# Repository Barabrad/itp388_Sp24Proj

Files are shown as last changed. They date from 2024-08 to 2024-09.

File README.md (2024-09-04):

# itp388_Sp24Proj
This is our group's project for ITP-388 in Spring 2024.

## Project Info
This project was compiled with the PlatformIO IDE extension in VSCode, so folders like `.vscode` or `test` were generated by the extension upon the creation of the project.

We used GitHub as we developed the software, and submitted it as part of our final deliverable in May 2024. However, I tidied up the repo (which required rebases) in August and September of 2024.

I also added the files we made that related to the hardware (3D-printing, PCBs, etc.) in the `Hardware` folder.

To see more about our project, visit [https://barabrad.github.io/engineering_portfolio/itp388proj](https://barabrad.github.io/engineering_portfolio/itp388proj)

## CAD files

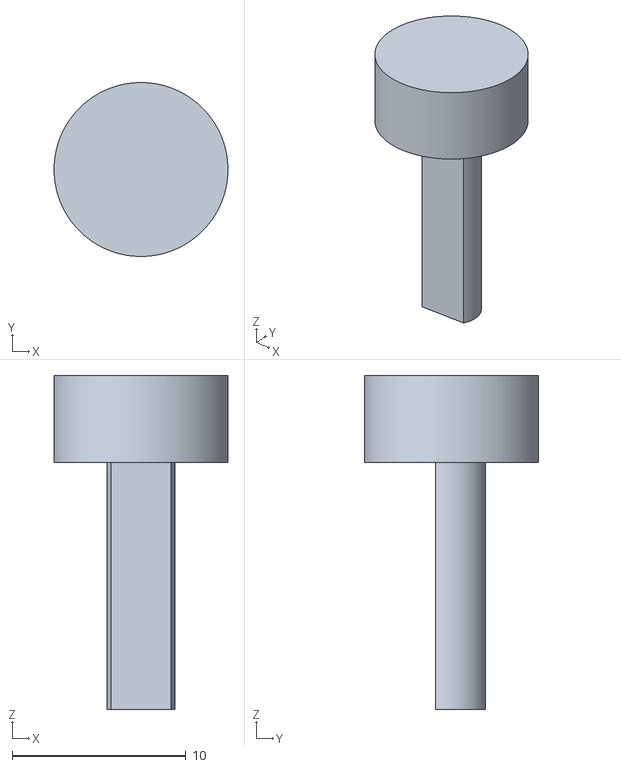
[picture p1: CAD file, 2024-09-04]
Hardware/STLs/Tilt Sensor Knob Round v2.stl
10.0 x 10.00 x 19.2

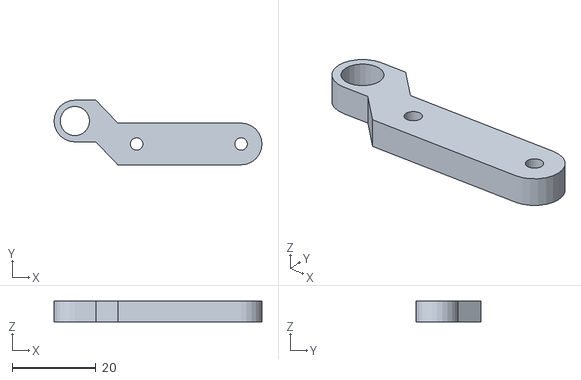
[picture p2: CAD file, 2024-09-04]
Hardware/STLs/Hinge.stl
49.8 x 15.5 x 5.00

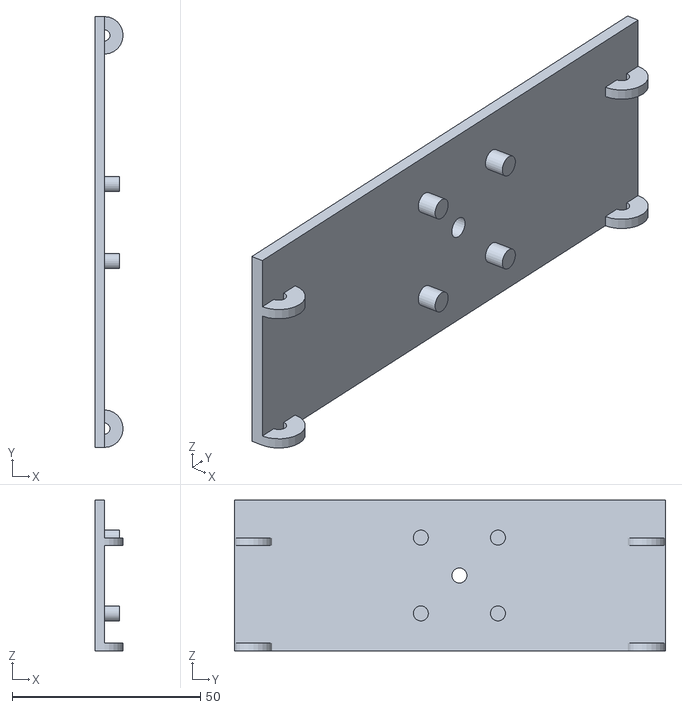
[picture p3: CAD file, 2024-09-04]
Hardware/STLs/InWall.stl
7.50 x 114.5 x 40.0

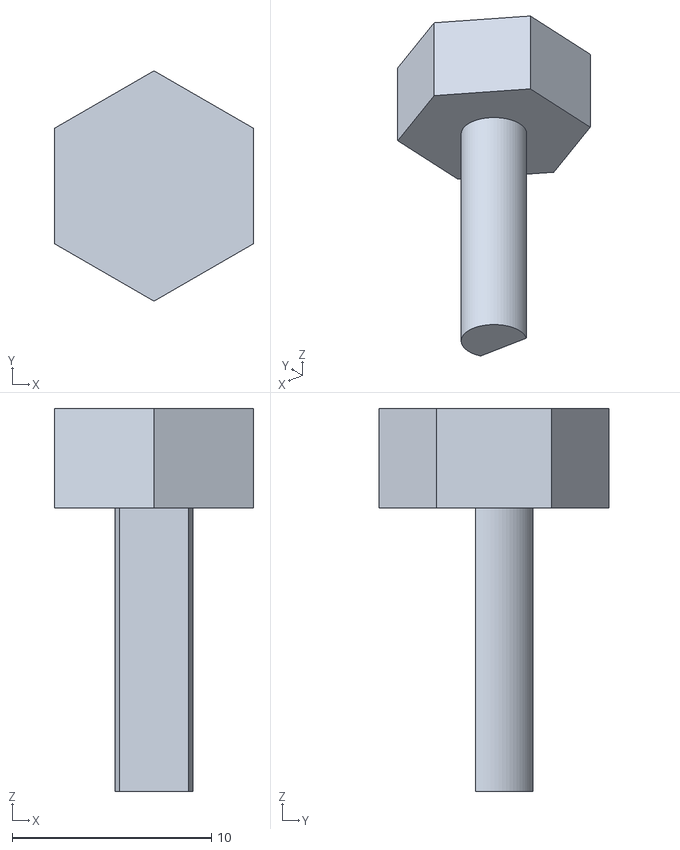
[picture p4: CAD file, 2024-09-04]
Hardware/STLs/Tilt Sensor Knob Hexagon v2.stl
10.0 x 11.5 x 19.2

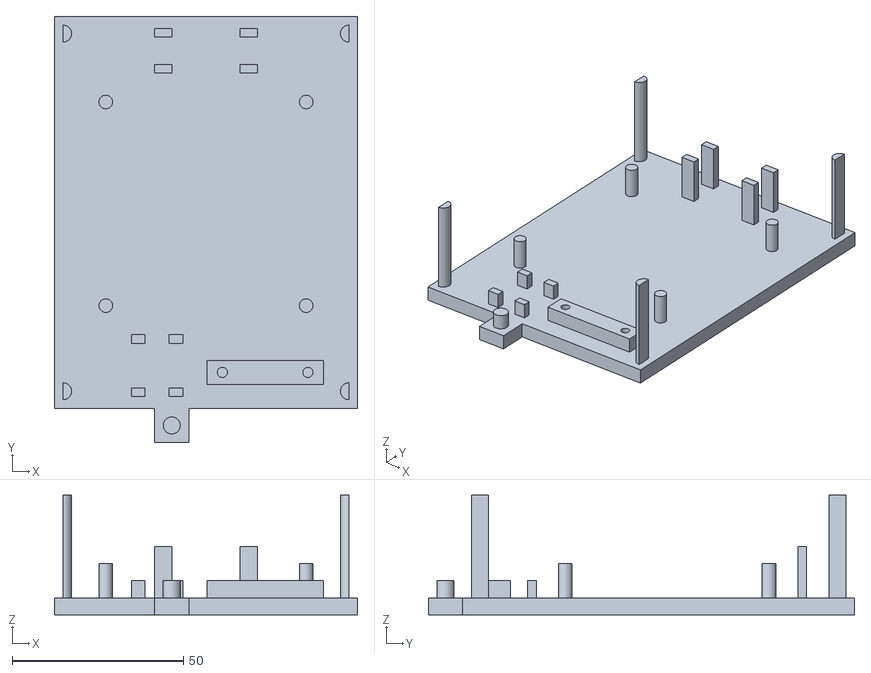
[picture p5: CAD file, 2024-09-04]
Hardware/STLs/EncBottom.stl
88.6 x 124.5 x 35.0

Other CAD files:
Hardware/STLs/InWall(Mirror).stl

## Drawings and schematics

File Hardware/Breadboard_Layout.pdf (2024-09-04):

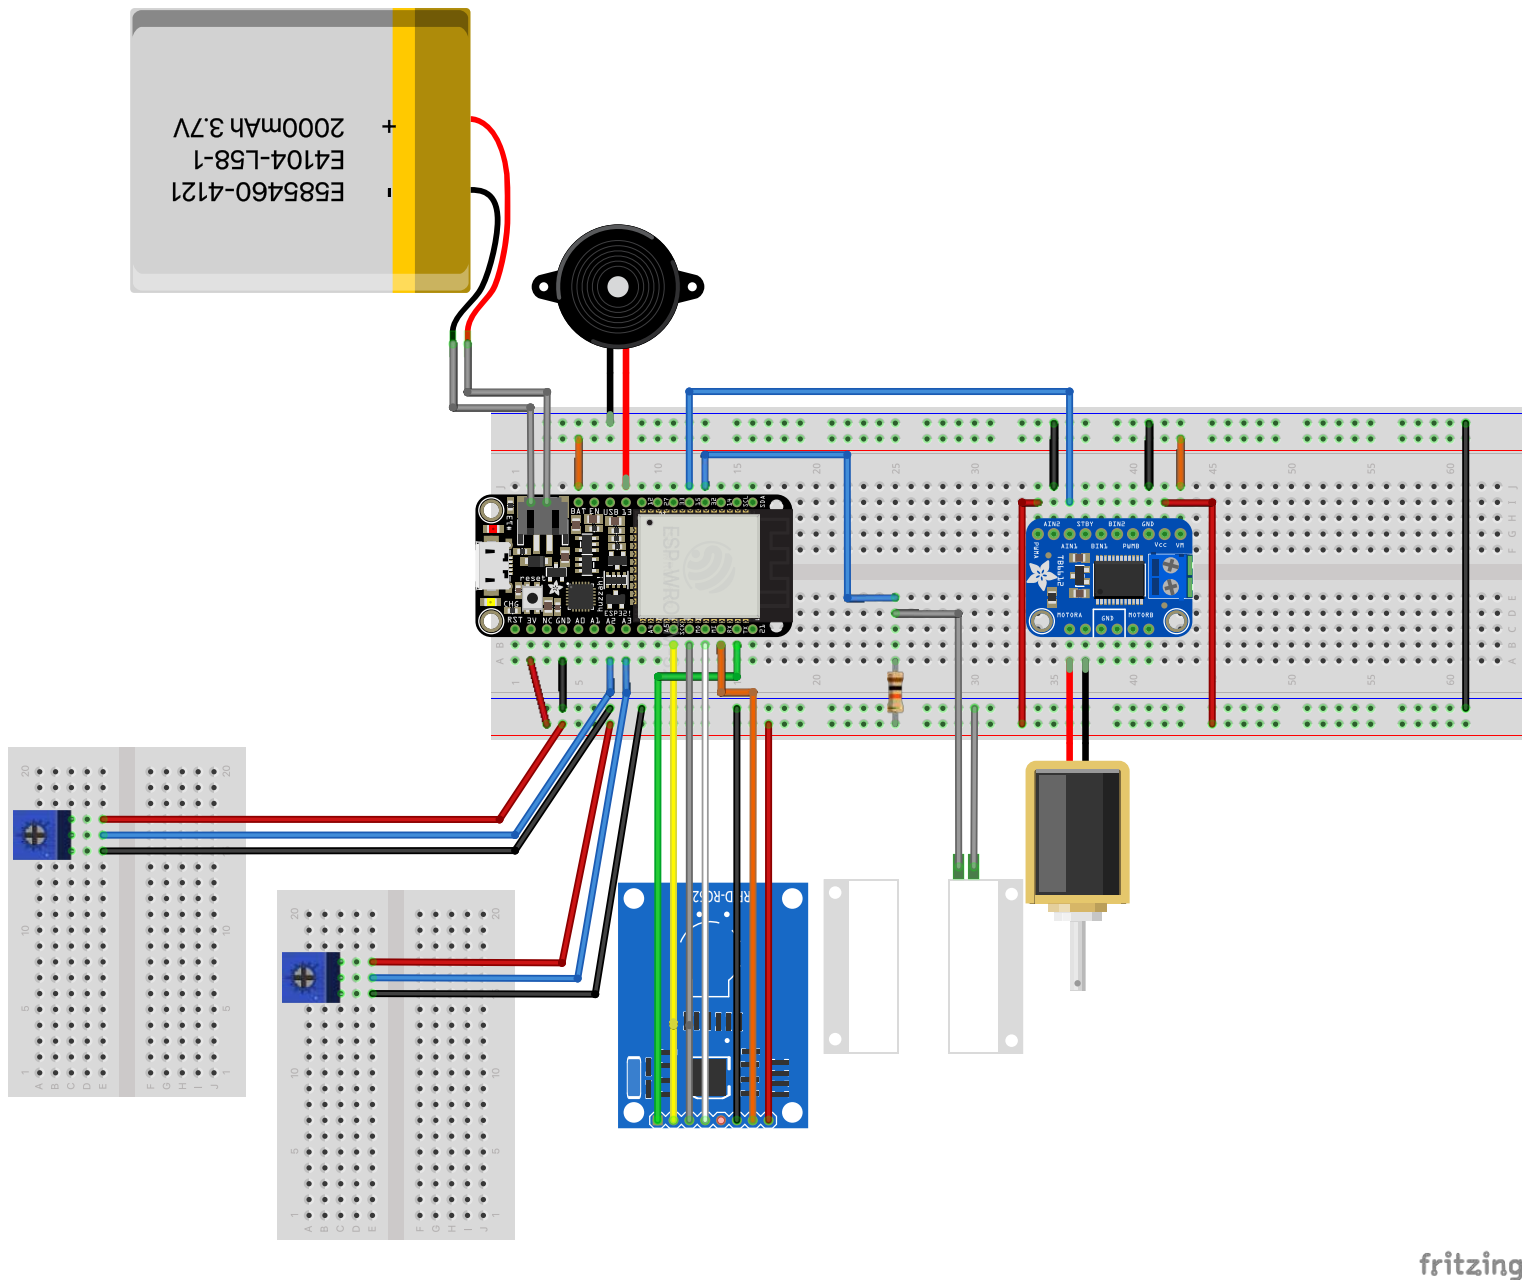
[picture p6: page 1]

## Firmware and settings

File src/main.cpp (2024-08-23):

// WiFi and Blynk Credentials
#include "secrets_def.h" // Default
//#include "secrets.h" // Specific (user must make this file)

#include <Arduino.h>
#include <WiFi.h>
#include <WiFiClient.h>
#include <BlynkSimpleEsp32.h>
#include "pitches.h"
#include <Wire.h> 
#include <MFRC522.h>
#include <SPI.h>

typedef unsigned long u_long;

// Your WiFi credentials.
// Set password to "" for open networks.
// https://examples.blynk.cc/?board=ESP32&shield=ESP32%20WiFi&example=GettingStarted%2FBlynkBlink
char ssid[] = SECRET_SSID;
char pass[] = SECRET_PASS;


// ***************************** //
// ***** Constant Globals ****** //
// ***************************** //
// Pins
const uint8_t BUZZER_PIN = 13; // Adjust values based on pin mapping
const uint8_t MAGSWITCH_PIN = 32;
const uint8_t TILT_IN_PIN = 34; // Tilt sensor on the inside
const uint8_t TILT_OUT_PIN = 39; // Tilt sensor on the outside (can override locking)
const uint8_t SOLENOID_PIN = 15;
const uint8_t SS_PIN = 17; // SDA for RFID Reader
const uint8_t RST_PIN = 16; // Reset for RFID Reader
const uint8_t BAT_PIN = A13; // https://learn.adafruit.com/adafruit-huzzah32-esp32-feather/power-management#measuring-battery-3122383
const uint8_t BUT_VAL_PIN = 21; // To simulate valid RFID swipe
const uint8_t BUT_INVAL_PIN = 23; // To simulate invalid RFID swipe
// Array for notes (zeros are rests)
const uint8_t BPM = 135; // Beats per minute
const float BPS = BPM/60.0; // Beats per second
const uint8_t NATURAL_GAP = 50; // Natural delay of switching note, ms
// Melody (valid card)
const uint8_t MELODY_LEN = 29; // # of notes (including rests)
const uint16_t MELODY[MELODY_LEN] = {NOTE_GS3, NOTE_AS3, NOTE_CS4, NOTE_AS3, NOTE_F4, NOTE_F4, NOTE_DS4, 0, NOTE_GS3, NOTE_AS3, NOTE_CS4, NOTE_AS3, NOTE_DS4, NOTE_DS4, NOTE_CS4, NOTE_C4, NOTE_AS3, NOTE_GS3, NOTE_AS3, NOTE_CS4, NOTE_AS3, NOTE_CS4, NOTE_DS4, NOTE_C4, NOTE_AS3, NOTE_GS3, NOTE_GS3, NOTE_DS4, NOTE_CS4};
const float MELODY_BEATS[MELODY_LEN] = {0.25, 0.25, 0.25, 0.25, 0.75, 0.75, 1, 0.5, 0.25, 0.25, 0.25, 0.25, 0.75, 0.75, 0.75, 0.25, 0.5, 0.25, 0.25, 0.25, 0.25, 1, 0.5, 0.75, 0.25, 1, 0.5, 1, 1};
// Tritone (invalid card)
const uint8_t TRITONE_LEN = 2; // # of notes (including rests)
const uint16_t TRITONE[TRITONE_LEN] = {NOTE_F5, NOTE_B4};
const float TRITONE_BEATS[TRITONE_LEN] = {0.5, 0.5};
// Warning
const uint8_t WARNING_LEN = 5; // # of notes (including rests)
const uint16_t WARNING[WARNING_LEN] = {NOTE_G5, NOTE_F5, NOTE_D5, NOTE_C5, NOTE_A4};
const float WARNING_BEATS[WARNING_LEN] = {0.5, 0.5, 0.5, 0.5, 1};
// Timing
const u_long TIME_OPEN = 15000; // 15 seconds
const u_long SCAN_DELAY = 5000; // 5 seconds
const u_long WARNING_DELAY = 10000; // 10 seconds
const u_long TIME_ACTUATE = 2000; // 2 seconds (to push the lock to close)
const u_long BAT_UPDATE = 60000; // 60 seconds
const u_long TIME_TBST = 5000; // 5 seconds for each troubleshoot packet

// ***************************** //
// **** Non-Const. Globals ***** //
// ***************************** //
// Timing
u_long prevMillisDoor = 0;
u_long prevMillisScan = 0;
u_long prevMillisWarning = 0;
u_long prevMillisSound = 0;
u_long prevMillisAct = 0;
u_long prevMillisBat = 0;
u_long prevMillisTbst = 0; // For troubleshooting tilt
// Controls
const bool DO_TBST = false; // Enable/disable troubleshooting packets
const bool USE_BUT_FOR_CARD = false; // Enable buttons for testing if RDID is unavailable
bool doorOpen = false;
bool prevActuated = false;
bool actuated = false;
//bool justCheckedRFID = false;
// Other
uint8_t tilt_position = 0;
float batVoltage = -1;
uint8_t overrideVal = 0;

// Initialize RFID reader
MFRC522 mfrc522(SS_PIN, RST_PIN); // Create MFRC522 instance.
String rfid = "";
const String VALID_CARDS[] = {"61 C5 7A 10"}; // The card that came with the reader
// RFID tag (for invalid demo): 03 E2 0C 50

// Unorganized variables for non-blocking speaker code
uint8_t noteIndex = 0;
bool grant_access = false;
bool deny_access = false;
bool warning = false;
u_long pauseBetweenNotes = 0;

// ***************************** //
// ***** Helper Functions ****** //
// ***************************** //
void playSongWithDelay(const uint16_t* melody, const float* beats, const uint8_t len) {
  // Just for now, we're going to use delay()
  // To calculate the note time, we will use the beats/sec and the number of beats for each note
  for (int i = 0; i < len; i++) {
    int note_i = melody[i];
    float beats_i = beats[i];
    // Goal: Play the note and have a delay
    int noteTime = (beats_i/BPS)*1000; // ms
    if (note_i != 0) {
      tone(BUZZER_PIN, note_i, noteTime);
    }
    delay(noteTime + NATURAL_GAP);
    // Uncomment the line below to troubleshoot melody
    //Serial.println("  Note #" + String(i) + " (" + String(beats_i) + " beats, f = " + String(note_i) + " Hz, t = " + String(noteTime) + " ms)");
  }
}

// Plays a sound given inputs of the notes array, duration (beats) array, and number of notes
void playSound(const uint16_t* melody, const float* beats, const int num_notes) {
  // For every note, play the note for its duration (pausing would make the code much more complex)
  if (millis() - prevMillisSound >= pauseBetweenNotes) {
    // Resets noteIndex and boolean variables if play_alarm is true or the last note has been played, without changing play_alarm itself so that the alarm can be played continuously until it is deactivated
    if (noteIndex >= num_notes) {
      noteIndex = 0;
      grant_access = false;
      deny_access = false;
      warning = false;
      pauseBetweenNotes = 0; // Resets pauseBetweenNotes for the next sound that is played
      noTone(BUZZER_PIN); // Stops buzzer
    }
    else {
      prevMillisSound = millis();
      int note_i = melody[noteIndex];
      float beats_i = beats[noteIndex];
      int noteTime = (beats_i/BPS)*1000; // ms
      // Plays the note, but with no duration (since duration is blocking)
      if (note_i == 0) {noTone(BUZZER_PIN);}
      else {tone(BUZZER_PIN, note_i);}
      pauseBetweenNotes = noteTime; // Gap in notes would be hard to do without blocking
      // Increments noteIndex after the note is played
      //Serial.println(String(noteIndex) + ": " + String(note_i) + " Hz");
      noteIndex = noteIndex + 1;
    }
  }
}

void selectSound() {
  if (grant_access) {
    playSound(MELODY, MELODY_BEATS, MELODY_LEN);
  } else if (deny_access) {
    playSound(TRITONE, TRITONE_BEATS, TRITONE_LEN);
  } else if (warning) {
    playSound(WARNING, WARNING_BEATS, WARNING_LEN);
  } //else no sound is played
}

// void grantAccess() {
//   // Play pleasant sound, disable actuator
//   playSongWithDelay(MELODY, MELODY_BEATS, MELODY_LEN);
//   Serial.println("Access granted!");
// }

// void denyAccess() {
//   // Play unpleasant sound, don't disable actuator
//   playSongWithDelay(TRITONE, TRITONE_BEATS, TRITONE_LEN);
//   Serial.println("Access denied.");
// }

// void warning() {
//   // Play warning sound, don't disable actuator
//   playSongWithDelay(WARNING, WARNING_BEATS, WARNING_LEN);
//   Serial.println("Warning.");
// }

void disableAct() {
  // Disable the actuator
  digitalWrite(SOLENOID_PIN, LOW);
  actuated = false;
}

void open() {
  // Open the door
  disableAct();
  doorOpen = true;
  prevMillisDoor = millis();
  Serial.println("Opening door...");
}

void close() {
  // Close the door
  digitalWrite(SOLENOID_PIN, HIGH);
  doorOpen = false;
  actuated = true;
  prevMillisAct = millis();
  Serial.println("Closing door...");
}

bool isTilted(const uint8_t TILT_PIN) {
  // Figure out how to read from tilt sensor
  tilt_position = map(analogRead(TILT_PIN), 0, 4095, 0, 342);
  // Serial.println("Tilt angle: " + String(tilt_position));
  // delay(500);
  //Serial.println(tilt_position); // For testing
  if (tilt_position >= 30 && tilt_position <= 120) { // Adjust values during testing
    Serial.println("Doorknob tilted.");
    return true;
  }
  return false; // Placeholder so we can verify code works
}

bool verifyRFID(String tag) {
  // Verify RFID card
  for (int i = 0; i < sizeof(VALID_CARDS)/sizeof(VALID_CARDS[0]); i++) {
    if (tag == VALID_CARDS[i]) {
      return true;
    }
  }
  return false;
}

String readRFID() {
  String scannedCard = "";
  if (mfrc522.PICC_IsNewCardPresent() == true) {
    if (mfrc522.PICC_ReadCardSerial() == true) {
      for (byte i = 0; i < mfrc522.uid.size; i++) {
        if (mfrc522.uid.uidByte[i] < 0x10) {
          scannedCard = scannedCard + " 0";
        } else {
          scannedCard = scannedCard + " ";
        }
        scannedCard = scannedCard + String(mfrc522.uid.uidByte[i], HEX);
      }
      scannedCard.toUpperCase();
      scannedCard.trim();
      Serial.println("Scanned card: " + scannedCard);
    }
  }
  return scannedCard;
}

BLYNK_WRITE(V2) {
  //prevLockVal = overrideVal;
  overrideVal = param.asInt(); // assigning incoming value from pin V2 to a variable
}

// ***************************** //
// ****** Main Functions ******* //
// ***************************** //
void setup() {
  Serial.begin(9600);
	Wire.begin(); 
  // Begin Blynk
  Blynk.begin(BLYNK_AUTH_TOKEN, ssid, pass);

  delay(2000);
  Blynk.virtualWrite(V1, 0); // Set initial actuation value to false
  Serial.println("Blynk initialized.");

  // Initialize RFID reader
  SPI.begin(); // Init SPI bus
  mfrc522.PCD_Init(); // Init MFRC522
  delay(1000); // Optional delay. Some board do need more time after init to be ready, see Readme
  mfrc522.PCD_DumpVersionToSerial(); // Show details of PCD - MFRC522 Card Reader details

  Serial.println("RFID initialized.");

  // Set up pins
  pinMode(BUZZER_PIN, OUTPUT);
  pinMode(MAGSWITCH_PIN, INPUT);
  pinMode(TILT_IN_PIN, INPUT);
  pinMode(TILT_OUT_PIN, INPUT);
  pinMode(SOLENOID_PIN, OUTPUT);
  pinMode(SS_PIN, OUTPUT);
  pinMode(RST_PIN, OUTPUT);
  pinMode(BAT_PIN, INPUT);
  pinMode(BUT_VAL_PIN, INPUT);
  pinMode(BUT_INVAL_PIN, INPUT);

  Serial.println("Setup complete.");
}

void loop() {
  Blynk.run();
  selectSound();
  prevActuated = actuated;
  // Check tilt values
  if ((millis() - prevMillisTbst > TIME_TBST) && DO_TBST) {
    prevMillisTbst = millis();
    int outer = map(analogRead(TILT_OUT_PIN), 0, 4095, 0, 342);
    int inner = map(analogRead(TILT_IN_PIN), 0, 4095, 0, 342);
    int valid = digitalRead(BUT_VAL_PIN);
    int invalid = digitalRead(BUT_INVAL_PIN);
    Serial.println("(O,I) = (" + String(outer) + "," + String(inner) + ")");
    Serial.println("(V,IV) = (" + String(valid) + "," + String(invalid) + ")");
  }
  // Measure battery voltage
  if ((millis() - prevMillisBat > BAT_UPDATE) || (batVoltage == -1)) {
    prevMillisBat = millis();
    // https://forums.adafruit.com/viewtopic.php?t=196384
    float halfVolt = analogRead(BAT_PIN);
    batVoltage = (halfVolt*2)*(3.3/4096); // 3.3 reference voltage; 12-bit ADC -> 4096 values
    Serial.println("Battery: " + String(batVoltage) + " V");
    Blynk.virtualWrite(V0, batVoltage);
  }
  // Checks actuator (can't keep on for long or else it burns out)
  if (actuated && (millis() - prevMillisAct > TIME_ACTUATE)) {
    prevMillisAct = millis();
    disableAct();
    Serial.println("Actuation time ended.");
  }
  // Checks RFID
  if (!USE_BUT_FOR_CARD) {rfid = readRFID();}
  else {
    if (digitalRead(BUT_VAL_PIN) == HIGH) {rfid = "8B A0 F0 13";}
    else if (digitalRead(BUT_INVAL_PIN) == HIGH) {rfid = "Nuh uh";}
    else {rfid = "";}
  }
  if (overrideVal == 1 && !doorOpen) {
    Serial.println("Access granted!");
    grant_access = true;
    //grantAccess();
    open();
  } else if ((rfid != "") && (millis() - prevMillisScan > SCAN_DELAY) && !doorOpen) {
    prevMillisScan = millis();
    if (verifyRFID(rfid)) {
      Serial.println("Access granted!");
      grant_access = true;
      //grantAccess();
      open();
    } else {
      Serial.println("Access denied.");
      deny_access = true;
      //denyAccess();
    }
  } else { // Everything after only runs if RFID check does not go through
    if (doorOpen && (millis() - prevMillisDoor > TIME_OPEN)) { // Time to close door
      if (digitalRead(MAGSWITCH_PIN) == LOW) { // Mag switch closed
        close();
        //doorOpen = false; // Redundant, since close() changes that variable
      } else if (digitalRead(MAGSWITCH_PIN) == HIGH && millis() - prevMillisWarning > WARNING_DELAY) { // Mag switch open
        Serial.println("Warning.");
        warning = true;
        //warning();
        prevMillisWarning = millis();
      }
    } else if (!doorOpen && isTilted(TILT_IN_PIN)) { // Door closed and tilted from inside, but without RFID read
      close();
      Serial.println("Warning: Attempted opening from inside");
      warning = true;
      //warning();
    } else if (!doorOpen && isTilted(TILT_OUT_PIN)) { // Door closed and tilted from outside, but without RFID read
      open();
      Serial.println("Opened from outside.");
      grant_access = true;
      //grantAccess();
    }
  }
  if (actuated != prevActuated) {Blynk.virtualWrite(V1, actuated);}
}

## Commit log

2024-08-23 Added Blynk Library
    Added Blynk library and basic buzzer stuff
    [main.cpp]
2024-08-23 Placeholders and Organizing
    I put placeholders to get rid of error messages, that way the code could be validated.
    I also did a little organizing and standardization of formatting for constant variables.
    [main.cpp]
2024-08-23 WiFi Credentials
    The specific WiFi credentials will be stored in "secrets.h" (a file that won't be shared on GitHub). The default one for the school's guest WiFi will be on GitHub.
    [main.cpp]
2024-08-23 additional rotary/actuator functionality
    additional rotary/actuator functionality
2024-08-23 Wiring Changes
    Accounted for which pins can read with WiFi, and made other adjustments
2024-08-23 Accounted for Outside Tilting
    Also fixed incompatibilities with previous and current sound-playing
    [main.cpp]
2024-08-23 Added Battery Reading
    The voltage from the plugged LiPo can now be read.
2024-08-23 Test with Buttons
    The new RFID reader wasn't soldered, but we used two buttons to simulate a valid and invalid read. We were able to connect the RFID reader in an unstable way, so we got the new card and tag IDs.
    [main.cpp]
2024-09-04 Tidying Repo
    Removed unused library from .pio/libdeps/featheresp32/ and added hardware-related files for the sake of completeness.
    [EncBottom.stl, Hinge.stl, InWall(Mirror).stl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]
